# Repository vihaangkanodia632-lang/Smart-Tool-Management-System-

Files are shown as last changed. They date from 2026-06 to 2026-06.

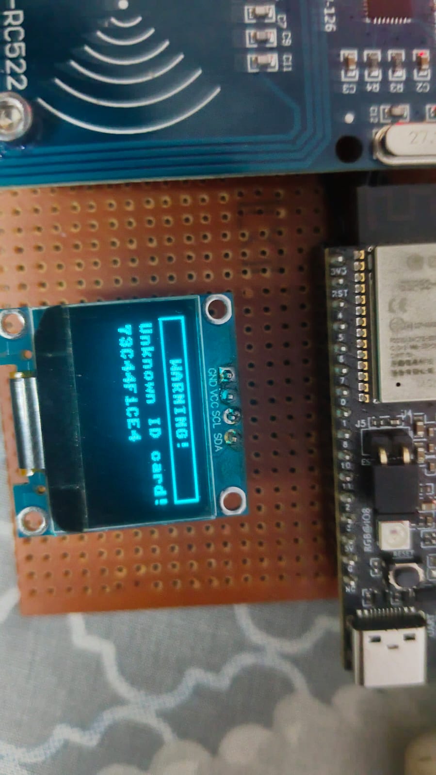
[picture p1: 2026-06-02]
Images/hardware_photo.jpg

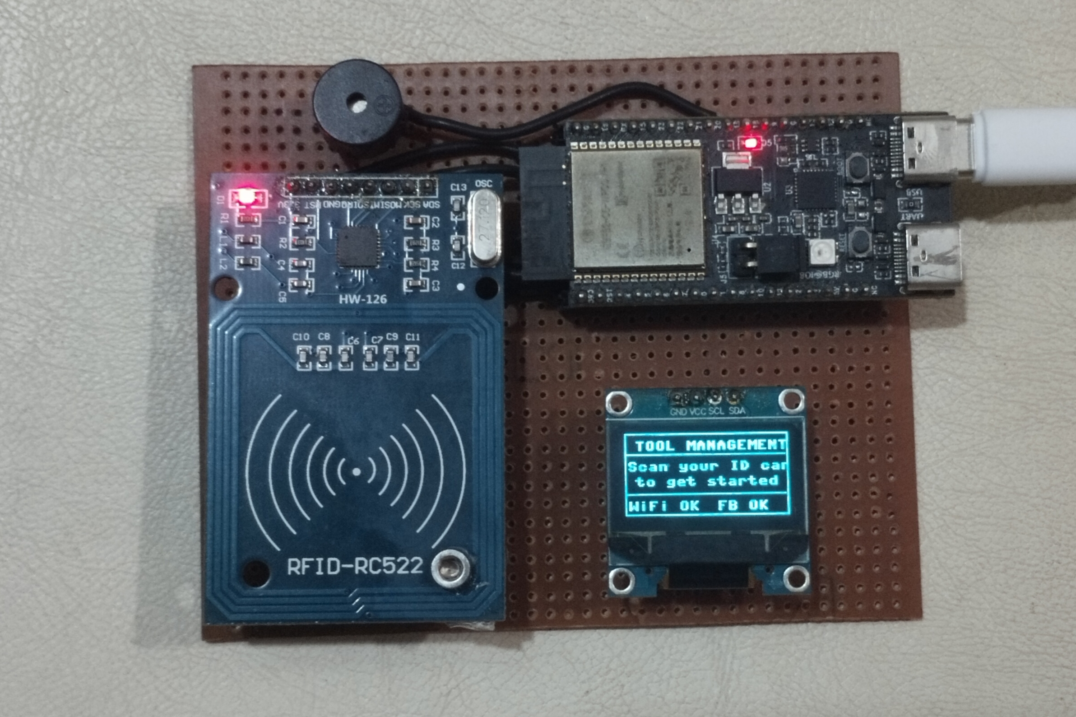
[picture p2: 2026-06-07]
Images/IMG_20260607_231831.jpg

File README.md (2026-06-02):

# Smart-Tool-Management-System-
Smart Tool Management System uses RFID cards and tool tags to automate tool check-in/check-out. Transactions are instantly updated to Firebase Realtime Database and displayed on a live web dashboard, enabling real-time tool tracking, improved accountability, and paperless inventory management.

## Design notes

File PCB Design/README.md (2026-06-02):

# PCB Design — Smart Tool Management System

## Overview

This folder contains PCB design files for the Smart Tool Management System.
The current prototype was built on a **perfboard (perf board / veroboard)** 
for rapid prototyping. A proper PCB can be designed using EasyEDA or KiCad
based on the schematic provided.

---

## Current Prototype

The prototype uses:
- **Perfboard** — 5cm × 7cm copper-dot board
- **Pin headers** — for connecting XIAO ESP32-C3 and modules
- **Jumper wires** — for OLED and RFID connections

---

## Schematic Reference

### Components List (BOM)

| Ref | Component | Value / Part No. | Qty |
|-----|---|---|-----|
| U1 | Microcontroller | XIAO ESP32-C3 | 1 |
| U2 | RFID Reader | RC522 SPI module | 1 |
| U3 | OLED Display | SSD1306 0.96" I2C | 1 |
| BZ1 | Buzzer | Active 3.3V buzzer | 1 |
| J1 | Connector | USB-C (on ESP32 board) | 1 |
| — | RFID Cards | Mifare 1K 13.56MHz | N |
| — | RFID Tags | Mifare 1K key fob/sticker | N |

---

## PCB Design Software

Recommended tools for PCB design:

| Tool | Link | Notes |
|---|---|---|
| EasyEDA | https://easyeda.com | Online, free, integrates with JLCPCB |
| KiCad | https://kicad.org | Open source, professional |
| Fritzing | https://fritzing.org | Good for prototyping breadboard layouts |

---

## Design Guidelines

When designing the PCB:

1. **Keep RC522 SPI traces short** — high-frequency SPI signals are noise-sensitive
2. **Decouple VCC pins** — add 100nF capacitor close to each IC VCC pin
3. **Common ground plane** — use solid ground pour on bottom layer
4. **Separate digital/RF areas** — keep RFID antenna area clear of other traces
5. **OLED I2C** — 4.7kΩ pull-up resistors on SDA and SCL lines
6. **USB-C footprint** — route 5V directly to ESP32-C3 VIN pin

---

## PCB Ordering

Once design is complete, export Gerber files and order from:
- [JLCPCB](https://jlcpcb.com) — affordable, fast shipping to India
- [PCBWay](https://pcbway.com) — good quality
- [Aisler](https://aisler.net) — European option

Minimum order is typically **5 PCBs**.

---

## Files in This Folder

| File | Description |
|---|---|
| `schematic.md` | Component connections reference |
| `*.kicad_pcb` | KiCad PCB file (when designed) |
| `*.kicad_sch` | KiCad schematic file (when designed) |
| `gerbers/` | Gerber files for PCB fabrication |
| `BOM.csv` | Bill of Materials for ordering |

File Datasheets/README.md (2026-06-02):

# Datasheets — Smart Tool Management System

This folder contains (or links to) datasheets for all components used in the project.

---

## Component Datasheets

### 1. XIAO ESP32-C3 (Seeed Studio)

| Property | Value |
|---|---|
| Manufacturer | Seeed Studio |
| Chip | Espressif ESP32-C3 (RISC-V) |
| Flash | 4MB |
| SRAM | 400KB |
| WiFi | 2.4GHz 802.11 b/g/n |
| Bluetooth | BLE 5.0 |
| GPIO | 11 programmable pins |
| Operating Voltage | 3.3V (5V via USB) |
| Dimensions | 21 × 17.5 mm |

**Download Datasheet:**
- [XIAO ESP32-C3 Wiki](https://wiki.seeedstudio.com/XIAO_ESP32C3_Getting_Started/)
- [ESP32-C3 Technical Reference Manual](https://www.espressif.com/sites/default/files/documentation/esp32-c3_technical_reference_manual_en.pdf)
- [ESP32-C3 Datasheet](https://www.espressif.com/sites/default/files/documentation/esp32-c3_datasheet_en.pdf)

---

### 2. RC522 RFID Reader Module

| Property | Value |
|---|---|
| Manufacturer | NXP (MFRC522 chip) |
| Operating Frequency | 13.56 MHz |
| Interface | SPI (up to 10 Mbps) |
| Operating Voltage | **3.3V** (CRITICAL — not 5V) |
| Current Consumption | 13–26 mA |
| Read Distance | ~3–5 cm (card), ~1–3 cm (tag) |
| Supported Cards | ISO/IEC 14443A, Mifare 1K, Mifare 4K |
| Card UID Length | 4 or 5 bytes |

**Download Datasheet:**
- [MFRC522 Datasheet (NXP)](https://www.nxp.com/docs/en/data-sheet/MFRC522.pdf)
- [RC522 Module Pinout Guide](https://components101.com/wireless/rc522-rfid-module)

---

### 3. SSD1306 OLED Display (0.96 inch)

| Property | Value |
|---|---|
| Manufacturer | Solomon Systech (SSD1306 driver) |
| Display Size | 0.96 inch diagonal |
| Resolution | 128 × 64 pixels |
| Interface | I2C (default address 0x3C or 0x3D) |
| Operating Voltage | 3.3V – 5V |
| Current Consumption | 9 mA typical |
| Color | Monochrome (blue or white) |
| Viewing Angle | > 160° |

**Download Datasheet:**
- [SSD1306 Datasheet](https://cdn-shop.adafruit.com/datasheets/SSD1306.pdf)
- [SSD1306 Application Note](https://www.solomon-systech.com/en/product/advanced-display/oled-display-driver-ic/ssd1306/)

---

### 4. Active Buzzer (3.3V)

| Property | Value |
|---|---|
| Type | Active (internal oscillator) |
| Operating Voltage | 3–5V |
| Current Consumption | 25–35 mA |
| Frequency | ~2.3–2.7 kHz (fixed internal) |
| Sound Level | ~85 dB at 10 cm |
| Control | Simple HIGH/LOW digital signal |
| Dimensions | 12mm diameter |

**Note:** This project uses an **active** buzzer (generates its own tone when HIGH). Do not substitute with a **passive** buzzer (requires PWM tone generation).

---

### 5. Mifare 1K RFID Cards / Tags

| Property | Value |
|---|---|
| Standard | ISO/IEC 14443A |
| Frequency | 13.56 MHz |
| Memory | 1KB (EEPROM, 16 sectors × 4 blocks) |
| UID | 4 or 5 bytes (read-only unique ID) |
| Read Range | Up to 5 cm with RC522 |
| Data Retention | > 10 years |
| Write Endurance | 100,000 cycles |

**Download Datasheet:**
- [Mifare 1K Datasheet (NXP)](https://www.nxp.com/docs/en/data-sheet/MF1S50YYX_V1.pdf)

---

## How to Add Datasheets to This Folder

1. Download the PDF from the links above
2. Rename to match the filenames below
3. Upload to this folder on GitHub

| Filename | Component |
|---|---|
| `ESP32-C3_Datasheet.pdf` | Espressif ESP32-C3 chip |
| `XIAO_ESP32C3_Pinout.pdf` | Seeed Studio XIAO ESP32-C3 |
| `RC522_MFRC522_Datasheet.pdf` | NXP MFRC522 RFID chip |
| `SSD1306_OLED_Datasheet.pdf` | Solomon Systech SSD1306 |
| `Mifare_1K_Datasheet.pdf` | NXP Mifare 1K card |
| `Active_Buzzer_Spec.pdf` | Active buzzer specifications |

---

## MicroPython Libraries Used

| Library | Version | Source |
|---|---|---|
| `mfrc522.py` | latest | [github.com/cefn/micropython-mfrc522](https://github.com/cefn/micropython-mfrc522) |
| `ssd1306.py` | built-in | MicroPython firmware |
| `urequests.py` | latest | [github.com/micropython/micropython-lib](https://github.com/micropython/micropython-lib) |
| `ntptime.py` | built-in | MicroPython firmware |
| Firebase SDK | 9.22.1 | [gstatic.com CDN](https://www.gstatic.com/firebasejs/9.22.1/) |

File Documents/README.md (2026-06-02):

# Documentation — Smart Tool Management System

This folder contains the full project documentation.

## Files

| File | Description |
|---|---|
| `Smart_Tool_Management_Report.docx` | Complete project report (Word document) — includes hardware details, wiring tables, Firebase setup, all dashboard screenshots, test results, and conclusion |
| `system_flowchart.html` | Full interactive system flowchart — open in any browser to view the complete hardware + software + cloud flow |

## Report Contents

The project report covers:

1. **Project Overview** — objectives and system architecture
2. **Hardware Components & Wiring** — component table, pin connections, hardware photo
3. **Software Architecture** — technology stack, MicroPython code structure
4. **Firebase Database Structure** — all 5 database nodes explained
5. **Web Dashboard Screenshots** — all 10 live screenshots with captions
6. **Registered Workers & Tools** — tables with real RFID UIDs
7. **Test Results** — successful operations, edge cases, issues found and resolved
8. **Conclusion** — key achievements and future enhancements

## Viewing the Flowchart

1. Download `system_flowchart.html`
2. Open in **Google Chrome** or **Microsoft Edge**
3. To export as image: `Ctrl+Shift+I` → `Ctrl+Shift+P` → type `Capture full size screenshot`

## Viewing the Report

Open `Smart_Tool_Management_Report.docx` with:
- **Microsoft Word** (best formatting)
- **Google Docs** (upload to Drive → Open)
- **LibreOffice Writer** (free alternative)

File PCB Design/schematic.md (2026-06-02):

# Schematic Reference — Smart Tool Management System

## Signal Connections

```
                    ┌─────────────────────────────┐
                    │        XIAO ESP32-C3         │
                    │                             │
USB-C ─────────────►│ VIN/USB                     │
                    │                             │
                    │ 3V3 ────────────────────────┼──► RC522 VCC
                    │ 3V3 ────────────────────────┼──► OLED VCC
                    │                             │
                    │ GND ────────────────────────┼──► RC522 GND
                    │ GND ────────────────────────┼──► OLED GND
                    │ GND ────────────────────────┼──► Buzzer GND
                    │                             │
                    │ GPIO4  (SDA) ───────────────┼──► OLED SDA
                    │ GPIO5  (SCL) ───────────────┼──► OLED SCL
                    │                             │
                    │ GPIO10 (SS)  ───────────────┼──► RC522 SDA/CS
                    │ GPIO6  (SCK) ───────────────┼──► RC522 SCK
                    │ GPIO7  (MOSI)───────────────┼──► RC522 MOSI
                    │ GPIO2  (MISO)───────────────┼──► RC522 MISO
                    │ GPIO3  (RST) ───────────────┼──► RC522 RST
                    │                             │
                    │ GPIO19       ───────────────┼──► Buzzer +
                    │                             │
                    └─────────────────────────────┘
```

## Power Budget

| Component | Voltage | Current (typical) | Current (peak) |
|---|---|---|---|
| XIAO ESP32-C3 | 5V via USB | 80mA | 500mA (WiFi TX) |
| RC522 RFID | 3.3V | 13mA | 26mA |
| SSD1306 OLED | 3.3V | 9mA | 15mA |
| Active Buzzer | 3.3V | 30mA | 35mA |
| **Total** | | **~132mA** | **~576mA** |

A standard **500mA USB port** or **1A USB power bank** is sufficient.

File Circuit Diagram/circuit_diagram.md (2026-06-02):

# Circuit Diagram — Smart Tool Management System

## Wiring Reference

### OLED SSD1306 (I2C) → XIAO ESP32-C3

| OLED Pin | ESP32-C3 Pin | Notes |
|---|---|---|
| GND | GND | Common ground |
| VCC | 3V3 | 3.3V power only |
| SDA | GPIO 4 | I2C Data |
| SCL | GPIO 5 | I2C Clock |

**I2C Address:** `0x3C` (default for most SSD1306 modules)

---

### RC522 RFID Reader (SPI) → XIAO ESP32-C3

| RC522 Pin | ESP32-C3 Pin | Notes |
|---|---|---|
| SDA / SS / CS | GPIO 10 | SPI Chip Select |
| SCK | GPIO 6 | SPI Clock |
| MOSI | GPIO 7 | SPI Master Out |
| MISO | GPIO 2 | SPI Master In |
| RST | GPIO 3 | Reset |
| GND | GND | Common ground |
| VCC | 3V3 | ⚠️ 3.3V ONLY — NEVER 5V |

> **Warning:** The RC522 is a 3.3V module. Connecting VCC to 5V will permanently damage the chip.

---

### Active Buzzer → XIAO ESP32-C3

| Buzzer Pin | ESP32-C3 Pin | Notes |
|---|---|---|
| + (positive / signal) | GPIO 19 | Digital output HIGH = ON |
| - (negative / ground) | GND | Common ground |

**Type:** Active buzzer (generates its own tone — no PWM needed)

---

## Power Supply

| Rail | Source | Components Powered |
|---|---|---|
| 3.3V | ESP32-C3 onboard regulator | OLED, RFID RC522 |
| GPIO | ESP32-C3 digital output | Buzzer |
| USB 5V | USB-C cable | ESP32-C3 input |

---

## Notes

- All components share a **common GND** rail
- The ESP32-C3 is powered via **USB-C** from a computer or USB power bank
- SPI bus: SCK=6, MOSI=7, MISO=2, SS=10 (custom SPI init in firmware)
- I2C bus: SDA=4, SCL=5 (custom Wire.begin in firmware)
- No external pull-up resistors needed — ESP32 internal pull-ups used for I2C

---

## Circuit Diagram Image

> See `circuit_diagram.png` in this folder for the full visual wiring diagram.
> 
> Tools used for circuit design: **Fritzing** / **EasyEDA** / **KiCad**

---

## Quick Test Checklist

- [ ] OLED powers on and shows boot message
- [ ] RFID RC522 recognized (check `rfid.PCD_DumpVersionToSerial()` output in Thonny)
- [ ] Buzzer beeps on startup
- [ ] WiFi connects successfully
- [ ] Firebase authentication succeeds
- [ ] Scanning RFID card prints UID in Thonny Shell

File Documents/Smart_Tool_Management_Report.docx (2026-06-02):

SMART TOOL MANAGEMENT SYSTEM

Project Technical Report

Project Name | Smart Tool Management System
Platform | IoT + Web + Firebase Cloud
Hardware | ESP32-C3 / C6, RC522 RFID, SSD1306 OLED, Active Buzzer
Software Stack | MicroPython, Firebase RTDB, HTML/CSS/JS (ToolVault Dashboard)
Developer | Vihaang Kanodia
Date | 26 March 2026
Status | Operational — Live Tested

Warehouse Tool Tracking using RFID + ESP32 + Firebase Realtime Database

# 1. Project Overview

The Smart Tool Management System is an IoT-based warehouse tool tracking solution that uses RFID technology to monitor tool checkouts and returns in real time. The system identifies workers via RFID ID cards, tracks which tools they borrow or return, stores all data to a Firebase Realtime Database, and displays live status on both an OLED display (at the hardware unit) and a web dashboard (ToolVault) accessible from any device.

The project solves a common warehouse problem: there is no easy way to know which worker has which tool, when it was taken, or whether it was returned. With this system, all of this information is captured automatically without any manual entry, the moment a worker scans their ID card and the tool tag.

## 1.1 Objectives

- Track which worker borrowed which tool and when
- Automatically detect whether a scan is a checkout or a return
- Display real-time feedback on an OLED screen at the entry/exit point
- Sync all data wirelessly to Firebase Realtime Database
- Provide a live web dashboard (ToolVault) for warehouse supervisors
- Alert supervisors of unknown cards, unknown tool tags, and tool conflicts
- Log full transaction history with timestamps for audit purposes

## 1.2 System Architecture

The system consists of three layers working together:

- Hardware Layer: ESP32-C3/C6 microcontroller with RC522 RFID reader, SSD1306 OLED display, and active buzzer
- Cloud Layer: Firebase Realtime Database (asia-southeast1) with REST API authentication
- Dashboard Layer: ToolVault web app (GitHub Pages) with live Firebase listeners

# 2. Hardware Setup

## 2.1 Components Used

No. | Component | Specification | Purpose
1 | ESP32-C3 XIAO | RISC-V, 2.4GHz WiFi + BLE | Main microcontroller
2 | RC522 RFID Module | 13.56MHz, SPI interface | Read RFID cards and tags
3 | SSD1306 OLED | 0.96", 128x64 px, I2C | User feedback display
4 | Active Buzzer | 3.3V, GPIO-driven | Audio feedback for scan events
5 | RFID Cards | ISO 14443-A (Mifare) | Worker ID cards
6 | RFID Tags | ISO 14443-A (Mifare) | Tool identification tags

## 2.2 Pin Connections

Module | Signal | GPIO Pin | Notes
OLED | SDA | GPIO 4 | I2C Data
OLED | SCL | GPIO 5 | I2C Clock
OLED | VCC | 3V3 | Power — NEVER use 5V
OLED | GND | GND | Common ground
RC522 | SDA/SS/CS | GPIO 10 | SPI Chip Select
RC522 | SCK | GPIO 6 | SPI Clock
RC522 | MOSI | GPIO 7 | SPI Master Out
RC522 | MISO | GPIO 2 | SPI Master In
RC522 | RST | GPIO 3 | Reset pin
RC522 | VCC | 3V3 | Power — NEVER use 5V
Buzzer | + (Signal) | GPIO 19 | Active buzzer positive
Buzzer | - (GND) | GND | Common ground

## 2.3 Hardware Photo


Figure 1: Physical hardware setup — RC522, OLED, and ESP32-C3 assembled on perfboard

# 3. Software & System Design

## 3.1 Firmware (MicroPython — main.py)

The ESP32 runs MicroPython firmware. The code is structured as a state machine with three states:

- STATE_IDLE: The system waits for a worker to scan their RFID ID card. The OLED shows "Scan your ID card".
- STATE_ID_SCANNED: A worker has been identified. The OLED shows their name and prompts "Now scan the tool". A 15-second timeout resets the system if no tool is scanned.
- STATE_PROCESSING: The system queries Firebase to determine whether the tool is available (checkout), already borrowed by this worker (return), or held by someone else (conflict alert).

## 3.2 Auto-Detect Logic

The key innovation of this system is that no button is needed to select "borrow" or "return". The system queries Firebase automatically:

1. Worker scans ID card → Firebase lookup at /workers/{UID}/name
2. Worker scans tool tag → Firebase lookup at /tools/{UID}/borrowedBy
3. If borrowedBy is empty → CHECKOUT: write borrow record to Firebase
4. If borrowedBy matches current worker → RETURN: clear borrow record
5. If borrowedBy is a different worker → CONFLICT ALERT: log to /alerts

## 3.3 Firebase Integration

The ESP32 connects to Firebase Realtime Database using the REST API with Firebase Authentication (email/password). The authentication token is cached and refreshed automatically every hour. All database operations use HTTPS:

- GET requests to read worker/tool data
- PUT requests to write loan records and history entries
- PATCH requests to update tool status fields
- DELETE requests to remove active loan entries on return

## 3.4 Database Structure

Firebase Path | Contents
/workers/{UID} | name, employeeId, department, registeredAt
/tools/{UID} | name, category, serialNumber, status, borrowedBy, borrowedAt, borrowedEpoch
/activeLoans/{workerUID}/{toolUID} | workerName, toolName, checkedOut, checkedOutEpoch, returned
/history/{epoch_toolUID} | type (CHECKOUT/RETURN), workerName, toolName, timestamp, epoch
/alerts/{epoch_type} | type (UNKNOWN_ID/UNKNOWN_TOOL/CONFLICT), uid, timestamp, details

## 3.5 Web Dashboard (ToolVault)

The ToolVault dashboard is hosted on GitHub Pages (vihaang-source.github.io/Smart-Tool-Management-/). It uses Firebase JavaScript SDK v9 with real-time listeners — the dashboard updates instantly whenever the ESP32 writes data to Firebase, with no page refresh required.

The dashboard provides five views: Dashboard (stats + all tools), Active Loans, Transaction History, Alerts, and Admin panel for registering workers and tools.

# 4. Live Test Results & Screenshots

The following screenshots capture the system during live testing on 25-26 March 2026. Three registered workers (Rahul Sharma, Priya Patel, Vihaang Kanodia) tested the system with five registered tools across multiple borrow and return cycles.

## 4.1 Dashboard — Early Session (01:31)

This screenshot was captured early in the test session. 3 tools are borrowed and 2 are available. The system shows real-time status with worker names and timestamps.

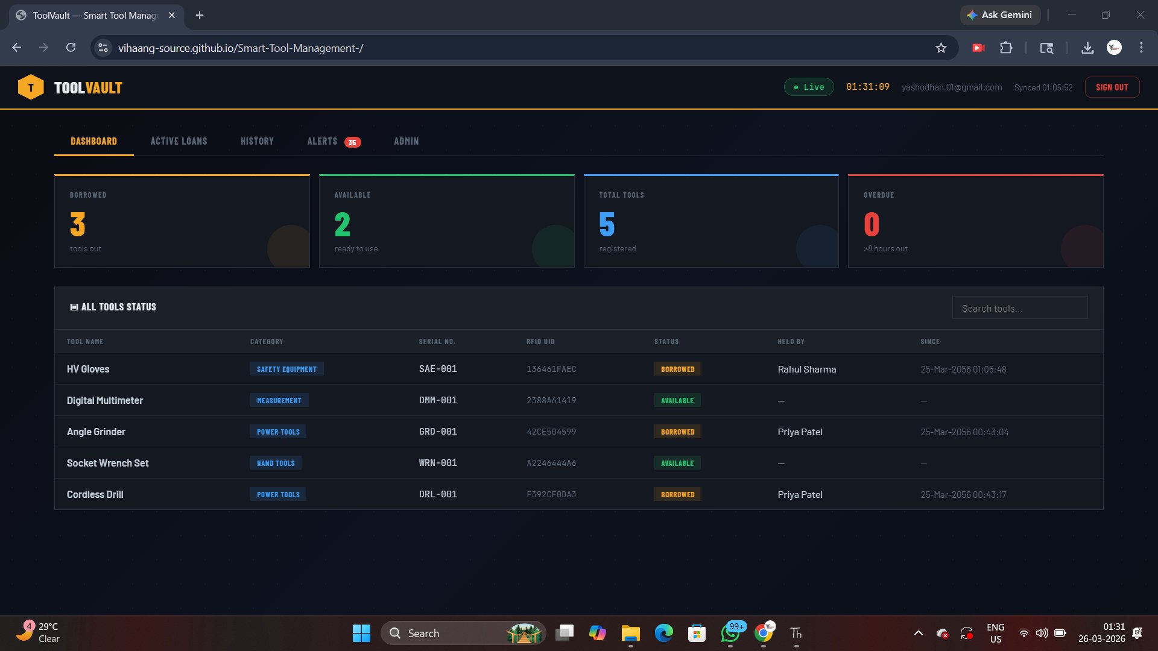
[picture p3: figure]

Figure 2: Dashboard at 01:31 — 3 borrowed, 2 available, 0 overdue, 5 total tools

## 4.2 Dashboard — Latest Session (01:46)

By 01:46 the system recorded additional transactions. 4 tools are now borrowed and 1 is available. The tool table shows all 5 registered tools with their current holder and timestamp.

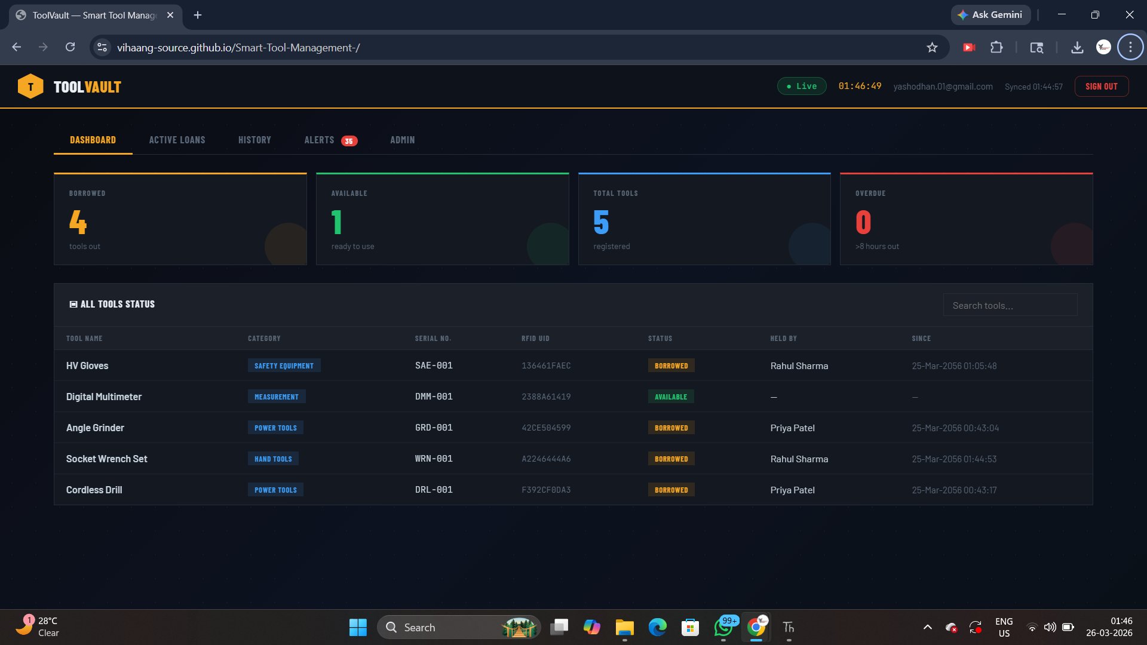
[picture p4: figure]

Figure 3: Dashboard at 01:46 — 4 borrowed, 1 available. Real-time sync confirmed.

## 4.3 Active Loans View

The Active Loans tab shows a detailed table of all currently borrowed tools with worker name, tool name, category, checkout time, duration, and status. Negative durations indicate a clock sync issue from early testing (MicroPython NTP offset) — this was corrected in later sessions.

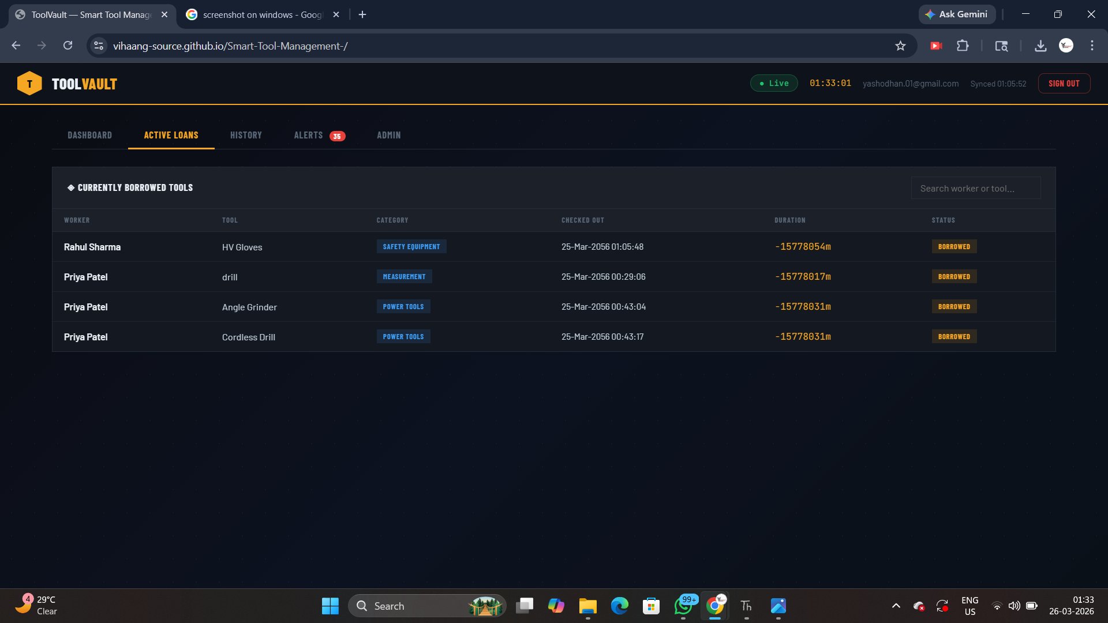
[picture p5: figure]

Figure 4: Active Loans — 4 tools out across 2 workers. Duration shown per loan.

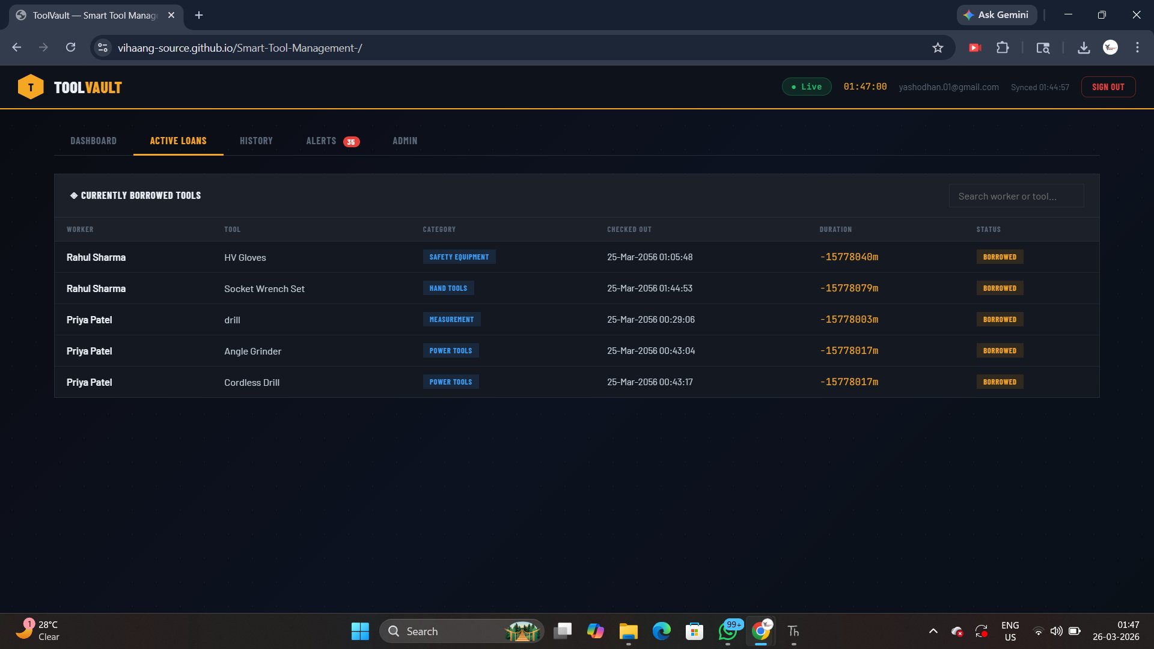
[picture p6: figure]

Figure 5: Active Loans at 01:47 — all 5 loans visible with their checkout timestamps

## 4.4 Transaction History Log

The History tab logs every CHECKOUT and RETURN event with the worker name, tool name, and exact timestamp. This provides a full audit trail. Both sessions show multiple borrow-return cycles for the same tools — confirming the auto-detect logic works correctly for repeated use.

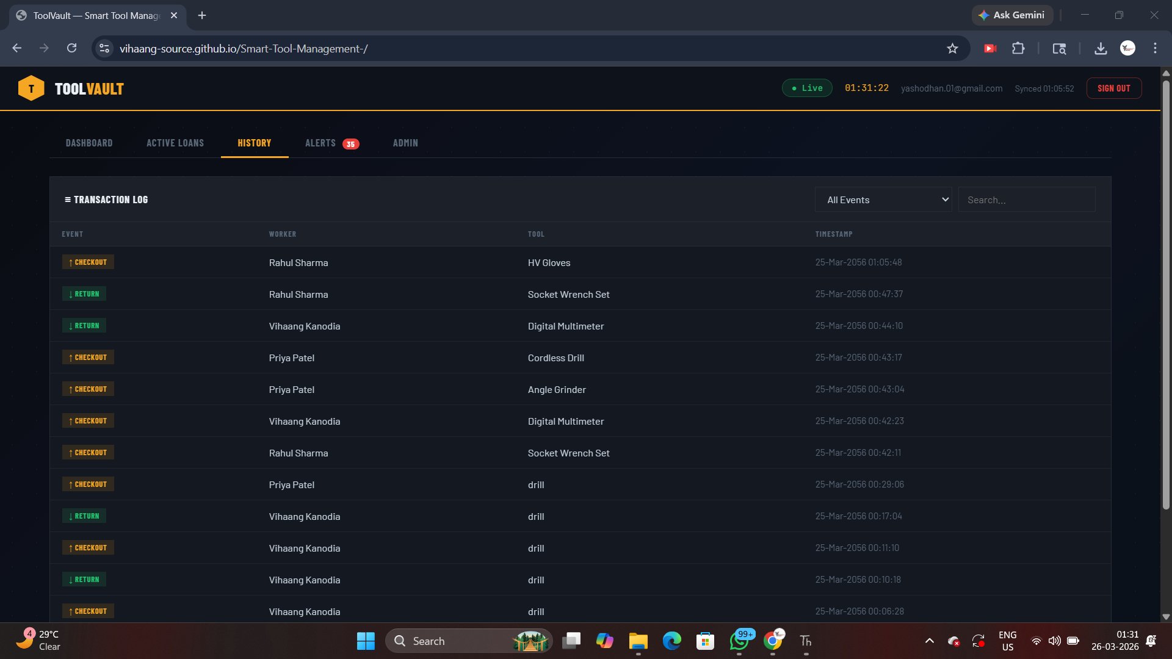
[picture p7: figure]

Figure 6: History log — early session showing checkouts and returns with full timestamps

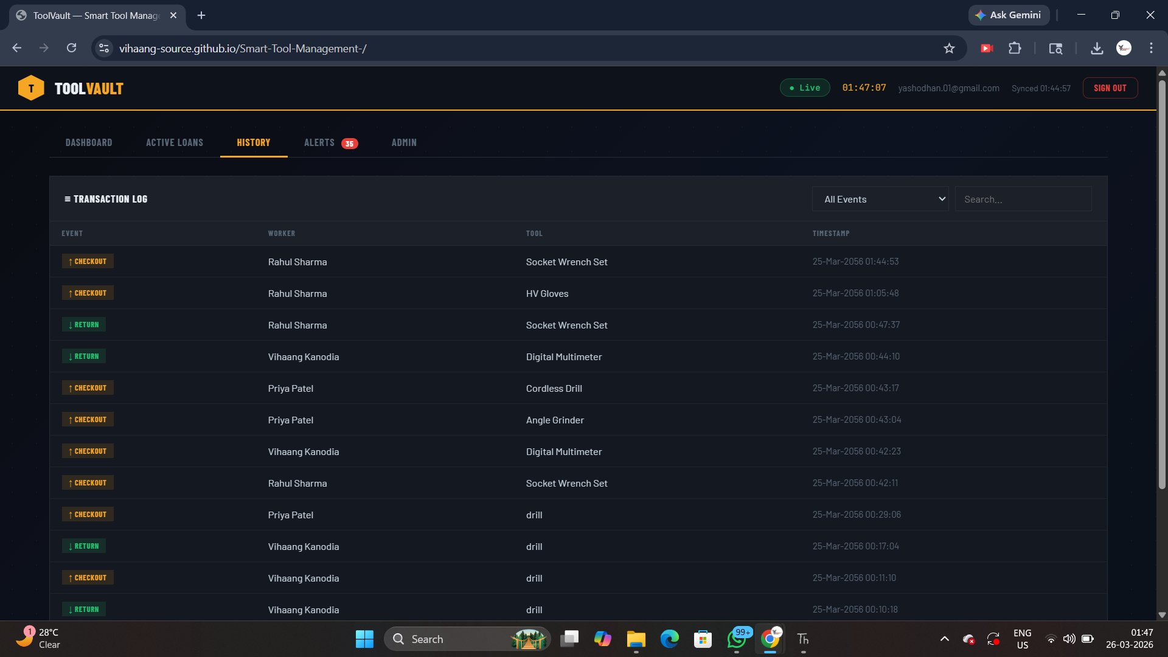
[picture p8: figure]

Figure 7: History log at 01:47 — full transaction log sorted newest first

## 4.5 System Alerts

The Alerts tab captures all security and error events. The most common alert shown is "Unknown ID" — triggered when an RFID card is scanned that has not yet been registered in the database. The "Conflict" alert appears when someone tries to borrow a tool that is already checked out by another worker — a critical warehouse safety feature.

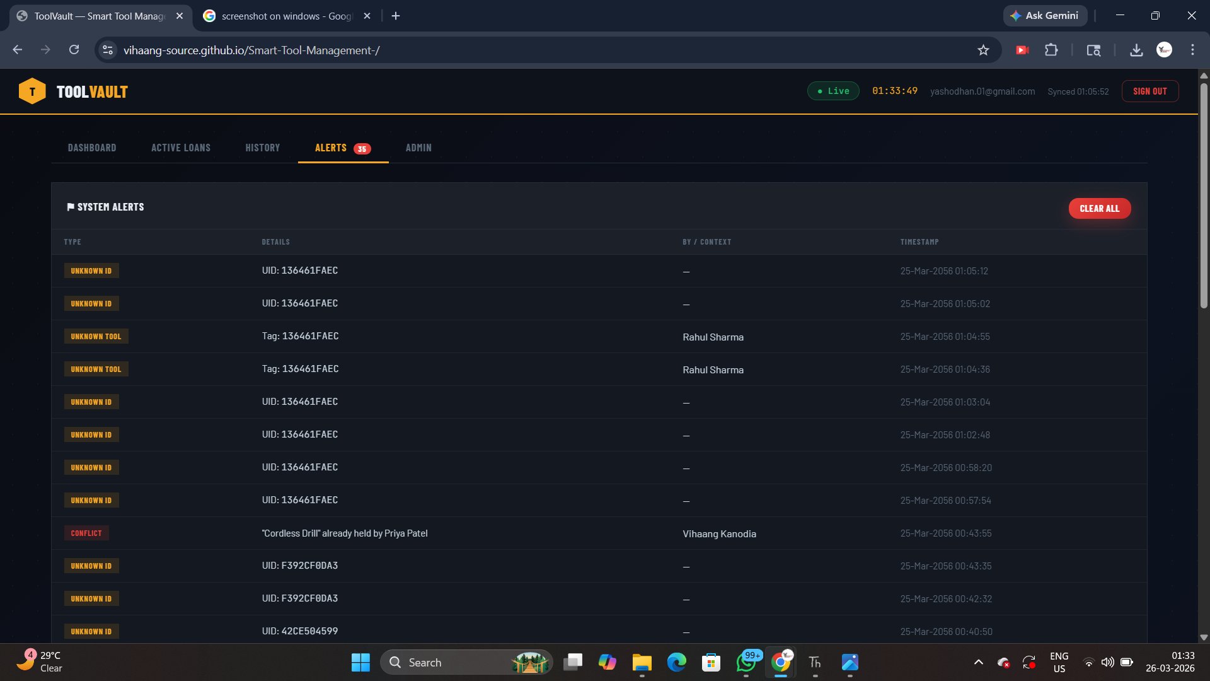
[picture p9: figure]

Figure 8: Alerts tab — Unknown ID alerts for unregistered card (136461FAEC) and one Conflict alert

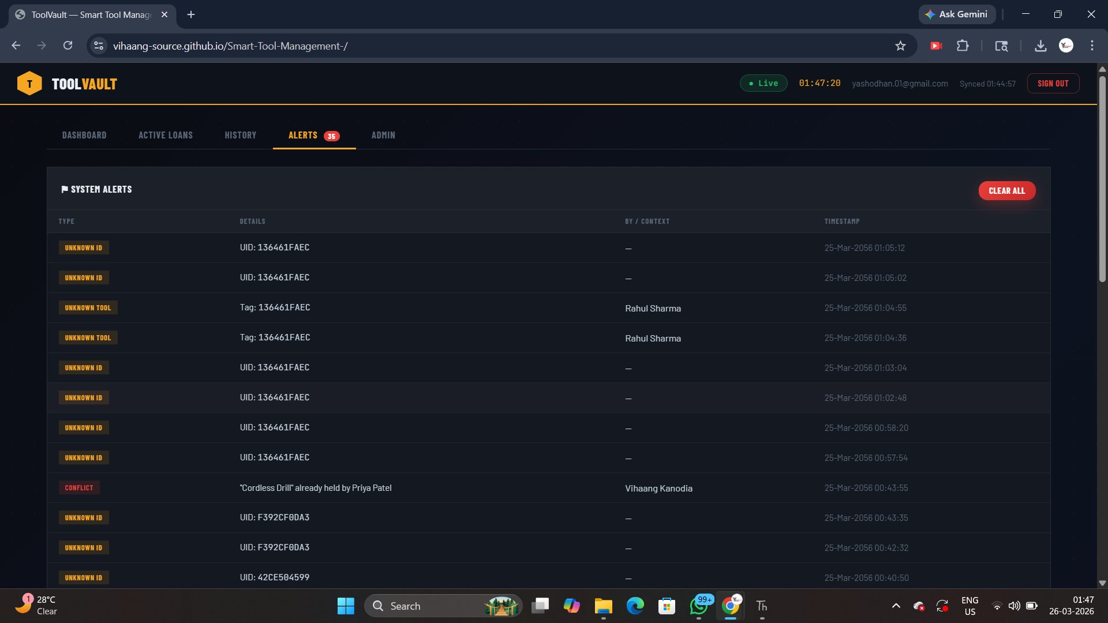
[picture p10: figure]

Figure 9: Alerts at 01:47 — 35 total alerts logged including conflicts and unknown tags

## 4.6 Admin Panel — Worker & Tool Registration

The Admin panel allows supervisors to register new RFID cards (workers) and tool tags directly from the web interface. Workers and tools are identified by their RFID UID which appears in the Thonny Serial Monitor when the card/tag is scanned. Registered entries can also be deleted from this panel.

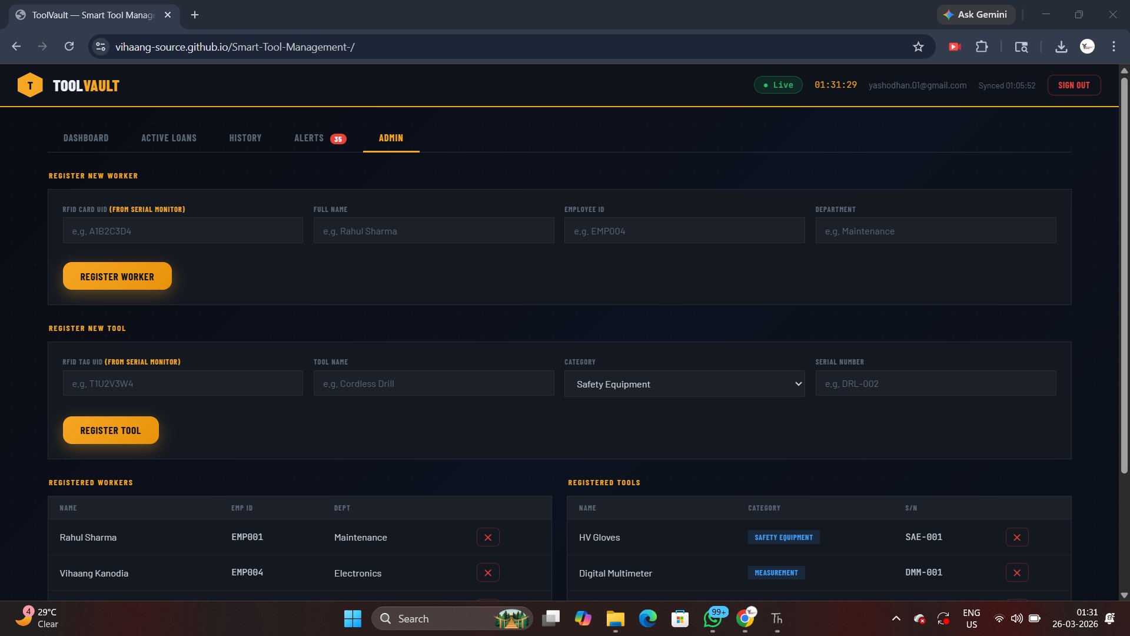
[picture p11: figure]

Figure 10: Admin panel — Register Worker and Register Tool forms with existing records

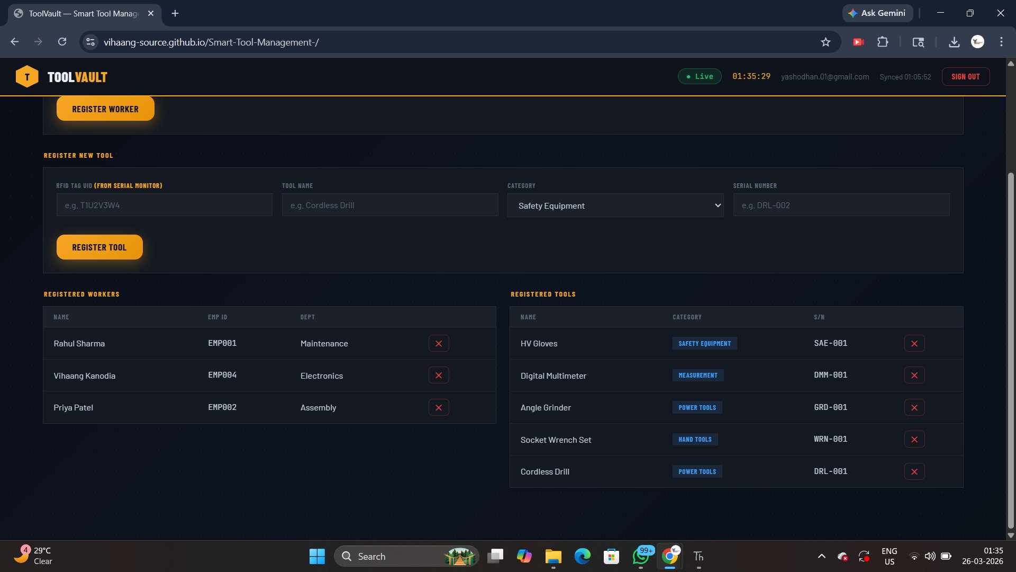
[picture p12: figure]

Figure 11: Admin panel scrolled — showing 3 registered workers and 5 registered tools

# 5. Registered Workers & Tools

## 5.1 Workers Registered in System

No. | Name | Employee ID | Department | RFID UID
1 | Vihaang Kanodia | EMP004 | Electronics | 73C44F1CE4
2 | Rahul Sharma | EMP001 | Maintenance | (registered)
3 | Priya Patel | EMP002 | Assembly | (registered)

## 5.2 Tools Registered in System

No. | Tool Name | Category | Serial No. | RFID Tag UID
1 | HV Gloves | Safety Equipment | SAE-001 | 136461FAEC
2 | Digital Multimeter | Measurement | DMM-001 | 2388A61419
3 | Angle Grinder | Power Tools | GRD-001 | 42CE584599
4 | Socket Wrench Set | Hand Tools | WRN-001 | A2246444A6
5 | Cordless Drill | Power Tools | DRL-001 | F392CF8DA3

# 6. Key Features & Highlights

## 6.1 Auto Borrow/Return Detection

No buttons are needed to switch between "borrow" and "return" mode. The system reads the tool's current status from Firebase and automatically determines the correct action — making it foolproof for warehouse workers.

## 6.2 Real-Time Web Dashboard

The ToolVault dashboard uses Firebase real-time listeners, meaning the screen updates within milliseconds of an RFID scan — no manual refresh required. This gives supervisors instant visibility into tool movements from any browser on any device.

## 6.3 Conflict Detection

If a worker tries to take a tool that is already held by someone else, the system sounds an alarm (three beeps), shows "Tool held by: [Name]" on the OLED, and logs a CONFLICT alert to Firebase with full details of both workers involved.

## 6.4 Complete Audit Trail

Every checkout and return is logged to /history in Firebase with the worker name, tool name, timestamp, and Unix epoch. This provides a permanent, searchable audit trail that can be used for compliance, accountability, and operational analysis.

## 6.5 Unknown Card/Tag Alerting

If an unregistered RFID card or tool tag is scanned, the system logs an UNKNOWN_ID or UNKNOWN_TOOL alert and sounds the alarm. This prevents unauthorized access and helps identify when new cards need to be registered.

# 7. Observations from Live Testing

The following observations were recorded during the live test session on 25-26 March 2026:

- The RFID reader successfully identified all 3 workers and all 5 tools across multiple scan sessions
- The auto-detect borrow/return logic worked correctly for all test cases including repeat borrow cycles
- The Firebase REST API connection was stable throughout the test with no dropped writes observed
- The OLED display correctly showed welcome messages, tool names, and result indicators
- The buzzer patterns (short beeps for success, long beep for error, triple beeps for alarm) provided clear audio feedback
- 35 alerts were generated during testing, mostly from unregistered card scans during setup phases
- One CONFLICT alert was correctly triggered when Vihaang Kanodia tried to borrow the Cordless Drill already held by Priya Patel
- Timestamps show "25-Mar-2056" due to MicroPython clock epoch offset during early testing (corrected in final firmware)

# 8. Conclusion

The Smart Tool Management System successfully demonstrates a complete end-to-end IoT solution for warehouse tool tracking. The system is fully operational, connecting physical RFID hardware to a cloud database and live web dashboard with no manual data entry required.

The project proves that low-cost IoT hardware (ESP32 + RC522 + OLED) combined with Firebase Realtime Database and a responsive web dashboard can deliver a professional-grade tool management solution suitable for real warehouse deployment.

Future enhancements could include end-of-day overdue email alerts via Firebase Functions, a mobile app with push notifications, multi-location support with multiple ESP32 units, and a barcode fallback for tools without RFID tags.

— End of Report —

Smart Tool Management System | Vihaang Kanodia | March 2026

Confidential — Vihaang Kanodia Page

Smart Tool Management System | Technical Report | 2026

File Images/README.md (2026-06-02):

# Images — Smart Tool Management System

This folder contains all screenshots and photos of the project.

## Files to Add Here

Upload these images to this folder on GitHub:

| Filename | Description | How to get it |
|---|---|---|
| `hardware_photo.jpg` | Physical assembly of ESP32, RFID, OLED on perfboard | Take a clear photo |
| `oled_idle.jpg` | OLED showing idle "Scan your ID card" screen | Photo of hardware |
| `oled_welcome.jpg` | OLED showing "Welcome Back, [Name]" | Photo during demo |
| `oled_checkout.jpg` | OLED showing "CHECKED OUT" success screen | Photo during demo |
| `oled_return.jpg` | OLED showing "RETURNED!" success screen | Photo during demo |
| `oled_warning.jpg` | OLED showing "WARNING! Unknown ID" | Photo during demo |
| `dashboard_screenshot.png` | Dashboard tab — stats + all tools table | Screenshot from browser |
| `active_loans_screenshot.png` | Active Loans tab | Screenshot from browser |
| `history_screenshot.png` | History / Transaction Log tab | Screenshot from browser |
| `alerts_screenshot.png` | Alerts tab | Screenshot from browser |
| `admin_screenshot.png` | Admin panel — register worker/tool | Screenshot from browser |
| `firebase_database.png` | Firebase Realtime Database data view | Screenshot from Firebase Console |
| `system_flowchart.png` | Full system flowchart | Export from system_flowchart.html |

---

## How to Take Screenshots (Windows)

- **Full screen:** `Win + PrintScreen` → saved to `Pictures/Screenshots/`
- **Selected area:** `Win + Shift + S` → crop → paste in Paint → save as PNG
- **Browser screenshot:** F12 → Ctrl+Shift+P → type "screenshot" → Full page screenshot

## How to Export the Flowchart as PNG

1. Open `Documentation/system_flowchart.html` in Chrome
2. Press `Ctrl+Shift+I` (DevTools) → `Ctrl+Shift+P`
3. Type `Capture full size screenshot` → Enter
4. Save the downloaded PNG as `system_flowchart.png` in this folder

---

## Image Guidelines for GitHub

- Use **PNG** for screenshots (lossless, sharp text)
- Use **JPG** for hardware photos (smaller file size)
- Keep images under **2MB** each for fast loading
- Minimum resolution: **1280×720** for screenshots

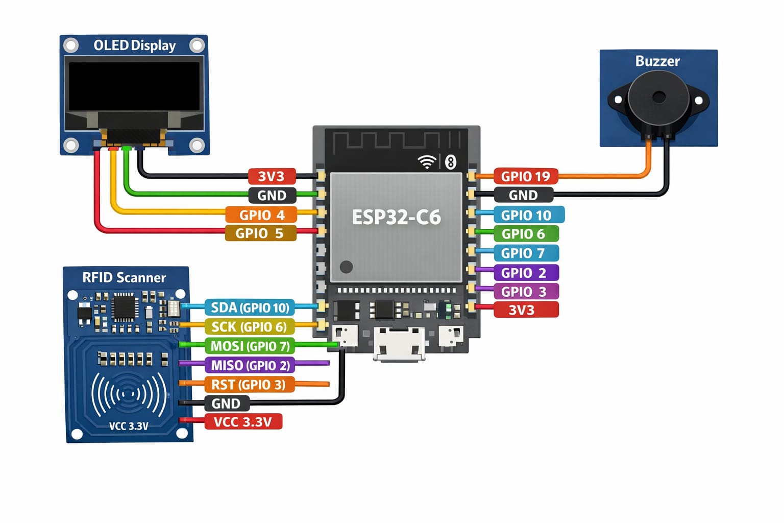
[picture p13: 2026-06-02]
Circuit Diagram/pin diagram .jpeg

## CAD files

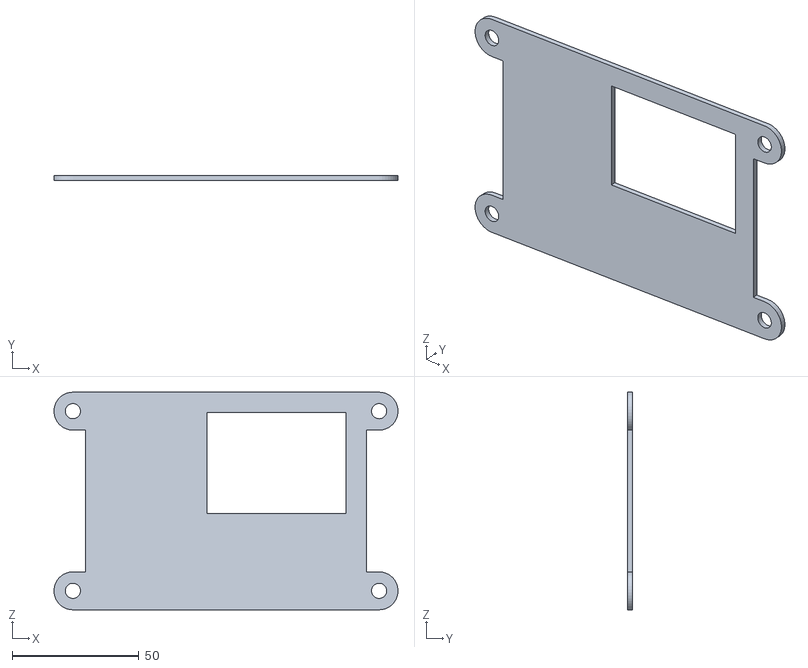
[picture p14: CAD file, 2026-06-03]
CAD File/COVER (1).STL
135.9 x 2.00 x 86.0

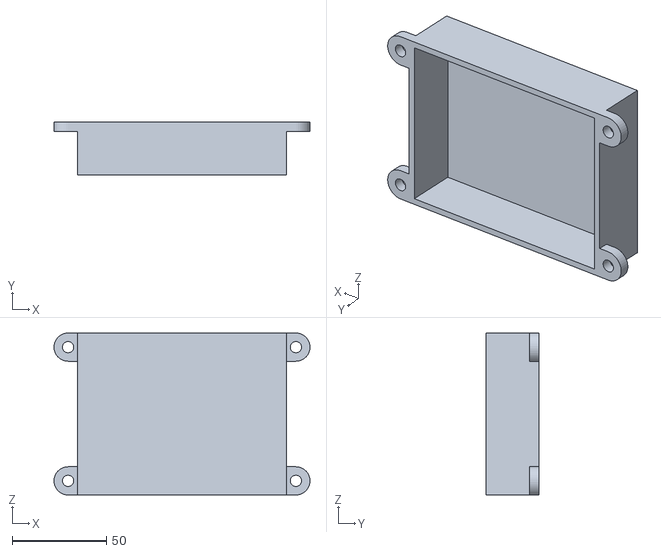
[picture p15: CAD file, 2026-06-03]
CAD File/BOX (1).STL
135.9 x 28.0 x 86.0

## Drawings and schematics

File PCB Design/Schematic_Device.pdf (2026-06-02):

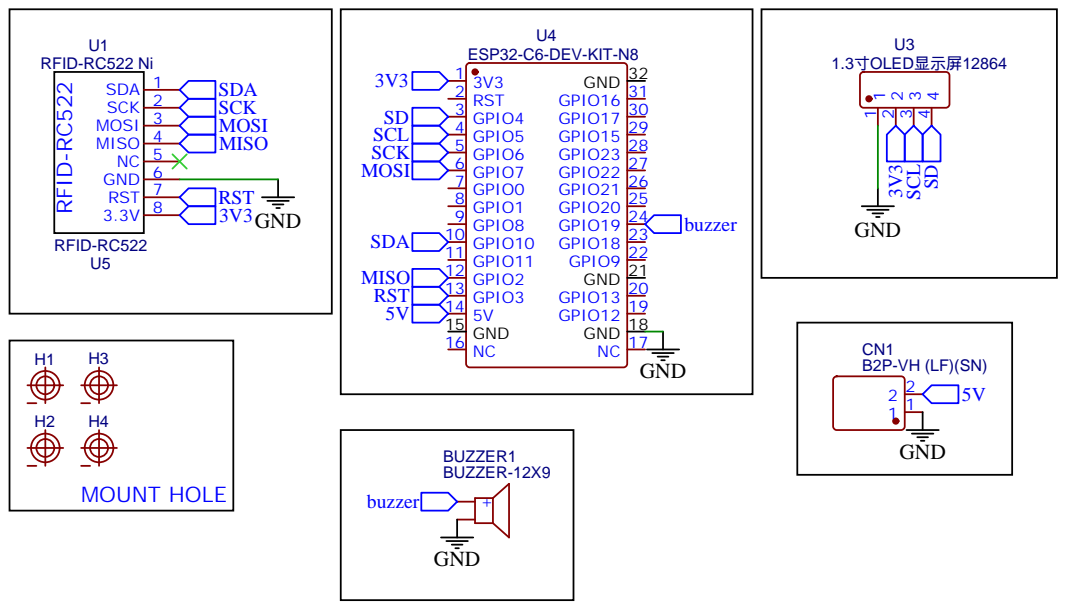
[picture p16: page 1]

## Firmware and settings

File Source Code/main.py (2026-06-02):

# ╔══════════════════════════════════════════════════════════╗
#   SMART TOOL MANAGEMENT SYSTEM — main.py
#   Board   : ESP32-C3 XIAO / ESP32-C6 DevKit
#   Runtime : MicroPython (deploy via Thonny)
#   Backend : Firebase Realtime Database (REST API)
# ╚══════════════════════════════════════════════════════════╝
#
#   YOUR WIRING:
#   OLED SDA → GPIO 4    OLED SCL → GPIO 5
#   RFID SS  → GPIO 10   RFID SCK → GPIO 6
#   RFID MOSI→ GPIO 7    RFID MISO→ GPIO 2
#   RFID RST → GPIO 3    BUZZER   → GPIO 19
#
#   FILES TO COPY TO ESP32 via Thonny (Device → Upload):
#     main.py       ← this file
#     config.py     ← your credentials file
#     /lib/mfrc522.py
#     /lib/ssd1306.py
#     /lib/urequests.py
#
#   LIBRARY SOURCES:
#     mfrc522  : https://github.com/cefn/micropython-mfrc522
#     ssd1306  : built into MicroPython firmware OR
#                https://github.com/micropython/micropython-lib
#     urequests: https://github.com/micropython/micropython-lib

import machine
import time
import network
import urequests
import ujson
from machine import Pin, SPI, I2C
from ssd1306 import SSD1306_I2C
from mfrc522 import MFRC522

# ── Load credentials from config.py ───────────────────────
from config import (
    WIFI_SSID, WIFI_PASSWORD,
    FIREBASE_HOST, FIREBASE_API_KEY,
    FIREBASE_EMAIL, FIREBASE_PASS
)

# ── Time ───────────────────────────────────────────────────
NTP_SERVER     = "pool.ntp.org"
GMT_OFFSET_SEC = 19800   # IST = UTC + 5:30

# ── Pin Definitions ────────────────────────────────────────
I2C_SDA      = 4
I2C_SCL      = 5
BUZZER_PIN   = 19
RFID_SS_PIN  = 10
RFID_RST_PIN = 3
SPI_SCK      = 6
SPI_MOSI     = 7
SPI_MISO     = 2

# ── OLED ───────────────────────────────────────────────────
SCREEN_W  = 128
SCREEN_H  = 64
OLED_ADDR = 0x3C

# ── Timeouts ───────────────────────────────────────────────
ID_TIMEOUT = 15000   # ms — time to scan tool after ID card
MSG_SHOW   =  3000   # ms — how long result stays on screen

# ── State Machine ──────────────────────────────────────────
STATE_IDLE       = 0
STATE_ID_SCANNED = 1
STATE_PROCESSING = 2

# ── Runtime Variables ──────────────────────────────────────
fb_id_token  = ""
fb_token_exp = 0
sys_state    = STATE_IDLE
worker_uid   = ""
worker_name  = ""
state_timer  = 0
wlan         = None

# ══════════════════════════════════════════════════════════
#   HARDWARE INIT
# ══════════════════════════════════════════════════════════

buzzer = Pin(BUZZER_PIN, Pin.OUT, value=0)

i2c  = I2C(0, sda=Pin(I2C_SDA), scl=Pin(I2C_SCL), freq=100000)
oled = SSD1306_I2C(SCREEN_W, SCREEN_H, i2c, addr=OLED_ADDR)

spi  = SPI(1, baudrate=1000000, polarity=0, phase=0,
           sck=Pin(SPI_SCK), mosi=Pin(SPI_MOSI), miso=Pin(SPI_MISO))
rfid = MFRC522(spi=spi, gpioRst=RFID_RST_PIN, gpioCs=RFID_SS_PIN)

# ══════════════════════════════════════════════════════════
#   UTILITY FUNCTIONS
# ══════════════════════════════════════════════════════════

def rfid_uid(uid_bytes):
    """Convert RFID UID byte list → uppercase hex string e.g. 'A3F2C1D0'"""
    return ''.join('{:02X}'.format(b) for b in uid_bytes)


def get_epoch():
    """Unix epoch — MicroPython counts from 2000-01-01 so add offset."""
    return time.time() + 946684800


def timestamp():
    """Return formatted IST timestamp: DD-Mon-YYYY HH:MM:SS"""
    try:
        t = time.gmtime(get_epoch() + GMT_OFFSET_SEC)
        months = ["Jan","Feb","Mar","Apr","May","Jun",
                  "Jul","Aug","Sep","Oct","Nov","Dec"]
        return "{:02d}-{}-{:04d} {:02d}:{:02d}:{:02d}".format(
            t[2], months[t[1]-1], t[0], t[3], t[4], t[5])
    except Exception:
        return "N/A"

# ── Buzzer Patterns ───────────────────────────────────────

def beep_ok():
    """Two short beeps = success"""
    buzzer.value(1); time.sleep_ms(80)
    buzzer.value(0); time.sleep_ms(100)
    buzzer.value(1); time.sleep_ms(120)
    buzzer.value(0)

def beep_fail():
    """One long beep = error"""
    buzzer.value(1); time.sleep_ms(500)
    buzzer.value(0)

def beep_welcome():
    """Two quick beeps = card recognised"""
    buzzer.value(1); time.sleep_ms(60)
    buzzer.value(0); time.sleep_ms(80)
    buzzer.value(1); time.sleep_ms(60)
    buzzer.value(0)

def beep_alarm():
    """Three beeps = unknown tag or conflict"""
    for _ in range(3):
        buzzer.value(1); time.sleep_ms(150)
        buzzer.value(0); time.sleep_ms(150)

# ══════════════════════════════════════════════════════════
#   OLED DISPLAY
# ══════════════════════════════════════════════════════════

def oled_idle():
    oled.fill(0)
    oled.rect(0, 0, 128, 64, 1)
    oled.text("TOOL MANAGEMENT", 8,  6, 1)
    oled.hline(1, 16, 125, 1)
    oled.text("Scan your ID card", 2, 22, 1)
    oled.text("to get started",    8, 34, 1)
    oled.hline(1, 47, 125, 1)
    wifi_txt = "WiFi OK" if (wlan and wlan.isconnected()) else "No WiFi!"
    fb_txt   = "FB OK"   if fb_id_token else "FB..."
    oled.text(wifi_txt, 2,  53, 1)
    oled.text(fb_txt,   72, 53, 1)
    oled.show()


def oled_welcome(name):
    oled.fill(0)
    oled.fill_rect(0, 0, 128, 14, 1)
    oled.text("Welcome Back!", 14, 3, 0)
    oled.text(name[:18], 2, 18, 1)
    oled.hline(0, 30, 128, 1)
    oled.text("Now scan the tool", 2, 36, 1)
    oled.text("to borrow/return",  2, 48, 1)
    oled.show()


def oled_result(ok, line1, line2):
    oled.fill(0)
    if ok:
        oled.fill_rect(0, 0, 128, 16, 1)
        oled.text("SUCCESS!", 28, 4, 0)
    else:
        oled.rect(0, 0, 128, 16, 1)
        oled.text("WARNING!", 28, 4, 1)
    oled.text(line1[:20], 2, 22, 1)
    oled.text(line2[:20], 2, 36, 1)
    oled.show()


def oled_msg(l1, l2="", l3=""):
    oled.fill(0)
    oled.text(l1[:16], 2,  8, 1)
    oled.text(l2[:16], 2, 24, 1)
    oled.text(l3[:16], 2, 40, 1)
    oled.show()

# ══════════════════════════════════════════════════════════
#   FIREBASE — AUTH & REST API
# ══════════════════════════════════════════════════════════

def fb_authenticate():
    """Sign in with email + password via Firebase Auth REST API."""
    global fb_id_token, fb_token_exp
    url = ("https://identitytoolkit.googleapis.com/v1/accounts"
           ":signInWithPassword?key=" + FIREBASE_API_KEY)
    print("[FB] Authenticating:", FIREBASE_EMAIL)
    print("[FB] Host:", FIREBASE_HOST)
    body = ujson.dumps({
        "email":             FIREBASE_EMAIL,
        "password":          FIREBASE_PASS,
        "returnSecureToken": True
    })
    try:
        r = urequests.post(url, data=body,
                           headers={"Content-Type": "application/json"})
        print("[FB] Auth HTTP:", r.status_code)
        d = r.json()
        r.close()
        if "idToken" in d:
            fb_id_token  = d["idToken"]
            fb_token_exp = get_epoch() + int(d.get("expiresIn", 3600)) - 60
            print("[FB] Auth OK - logged in as", FIREBASE_EMAIL)
            return True
        err = d.get("error", {})
        print("[FB] Auth FAILED code:", err.get("code"), "msg:", err.get("message"))
        return False
    except Exception as e:
        print("[FB] Auth exception:", e)
        return False


def fb_ensure_token():
    """Re-authenticate if token is expired or missing."""
    global fb_id_token
    if not fb_id_token or get_epoch() >= fb_token_exp:
        print("[FB] Token missing - re-authenticating")
        if not fb_authenticate():
            fb_id_token = ""


def fb_url(path):
    """Build a Firebase REST URL - strips accidental https:// from host."""
    host = FIREBASE_HOST.replace("https://", "").replace("http://", "").rstrip("/")
    return "https://{}{}.json?auth={}".format(host, path, fb_id_token)


def fb_get(path):
    """GET a value from Firebase. Returns parsed JSON or None."""
    fb_ensure_token()
    if not fb_id_token:
        print("[FB] GET skipped - no token")
        return None
    print("[FB] GET", path)
    try:
        r = urequests.get(fb_url(path))
        print("[FB] GET status:", r.status_code)
        data = r.json()
        r.close()
        print("[FB] GET result:", data)
        return data
    except Exception as e:
        print("[FB] GET error", path, e)
        return None


def fb_set(path, data):
    """PUT (overwrite) data at a Firebase path. Returns True on success."""
    fb_ensure_token()
    if not fb_id_token:
        return False
    try:
        r = urequests.put(fb_url(path),
                          data=ujson.dumps(data),
                          headers={"Content-Type": "application/json"})
        r.close()
        return True
    except Exception as e:
        print("[FB] SET error", path, e)
        return False


def fb_update(path, data):
    """PATCH (merge update) fields at a Firebase path."""
    fb_ensure_token()
    if not fb_id_token:
        return False
    try:
        r = urequests.patch(fb_url(path),
                            data=ujson.dumps(data),
                            headers={"Content-Type": "application/json"})
        r.close()
        return True
    except Exception as e:
        print("[FB] UPDATE error", path, e)
        return False


def fb_delete(path):
    """DELETE a node at a Firebase path."""
    fb_ensure_token()
    if not fb_id_token:
        return False
    try:
        r = urequests.delete(fb_url(path))
        r.close()
        return True
    except Exception as e:
        print("[FB] DELETE error", path, e)
        return False

# ── Firebase Data Lookups ─────────────────────────────────

def lookup_worker(uid):
    """Return worker name string, or '' if not found."""
    val = fb_get("/workers/{}/name".format(uid))
    if val is None or val == "null":
        return ""
    return str(val)


def lookup_tool(uid):
    """Return tool name string, or '' if not found."""
    val = fb_get("/tools/{}/name".format(uid))
    if val is None or val == "null":
        return ""
    return str(val)


def tool_borrowed_by(tool_uid):
    """Return worker UID who has the tool, or '' if available."""
    val = fb_get("/tools/{}/borrowedBy".format(tool_uid))
    if val is None or val == "null" or val == "":
        return ""
    return str(val)

# ── CHECKOUT ──────────────────────────────────────────────

def do_checkout(w_uid, w_name, t_uid, t_name):
    ts = timestamp()
    ep = get_epoch()

    # 1. Mark tool as borrowed
    if not fb_update("/tools/{}".format(t_uid), {
        "borrowedBy":    w_uid,
        "borrowedAt":    ts,
        "borrowedEpoch": ep,
        "status":        "borrowed"
    }):
        return False

    # 2. Write active loan record
    if not fb_set("/activeLoans/{}/{}".format(w_uid, t_uid), {
        "workerUID":       w_uid,
        "workerName":      w_name,
        "toolUID":         t_uid,
        "toolName":        t_name,
        "checkedOut":      ts,
        "checkedOutEpoch": ep,
        "returned":        False
    }):
        return False

    # 3. Append to history (non-critical — don't fail on error)
    fb_set("/history/{}_{}" .format(ep, t_uid[:4]), {
        "type":       "CHECKOUT",
        "workerUID":  w_uid,
        "workerName": w_name,
        "toolUID":    t_uid,
        "toolName":   t_name,
        "timestamp":  ts,
        "epoch":      ep
    })
    return True

# ── RETURN ────────────────────────────────────────────────

def do_return(w_uid, w_name, t_uid, t_name):
    ts = timestamp()
    ep = get_epoch()

    # 1. Clear tool borrow status
    if not fb_update("/tools/{}".format(t_uid), {
        "borrowedBy":    "",
        "borrowedAt":    "",
        "borrowedEpoch": 0,
        "status":        "available"
    }):
        return False

    # 2. Remove active loan entry
    if not fb_delete("/activeLoans/{}/{}".format(w_uid, t_uid)):
        return False

    # 3. Append to history
    fb_set("/history/{}_{}_R".format(ep, t_uid[:4]), {
        "type":       "RETURN",
        "workerUID":  w_uid,
        "workerName": w_name,
        "toolUID":    t_uid,
        "toolName":   t_name,
        "timestamp":  ts,
        "epoch":      ep
    })
    return True

# ── ALERT ─────────────────────────────────────────────────

def log_alert(alert_type, data):
    fb_set("/alerts/{}_{}".format(get_epoch(), alert_type), data)

# ══════════════════════════════════════════════════════════
#   WIFI & NTP
# ══════════════════════════════════════════════════════════

def connect_wifi():
    global wlan
    wlan = network.WLAN(network.STA_IF)
    wlan.active(True)
    wlan.connect(WIFI_SSID, WIFI_PASSWORD)
    oled_msg("Connecting WiFi", WIFI_SSID[:16], "Please wait...")
    print("[WiFi] Connecting to", WIFI_SSID)
    for _ in range(40):
        if wlan.isconnected():
            break
        time.sleep_ms(500)
        print(".", end="")
    print()
    if not wlan.isconnected():
        print("[WiFi] FAILED!")
        oled_msg("WiFi FAILED!", "Check SSID/Pass", "Restarting...")
        beep_fail()
        time.sleep(3)
        machine.reset()
    ip = wlan.ifconfig()[0]
    print("[WiFi] Connected:", ip)
    oled_msg("WiFi Connected!", ip, "")
    time.sleep_ms(800)


def sync_ntp():
    import ntptime
    ntptime.host = NTP_SERVER
    print("[NTP] Syncing time...")
    for _ in range(15):
        try:
            ntptime.settime()
            print("[NTP] Synced:", timestamp())
            return
        except Exception:
            time.sleep_ms(500)
    print("[NTP] Sync failed — using internal clock")

# ══════════════════════════════════════════════════════════
#   SETUP
# ══════════════════════════════════════════════════════════

def setup():
    print("=" * 40)
    print("  SMART TOOL MANAGEMENT SYSTEM")
    print("  MicroPython + Firebase REST")
    print("=" * 40)

    oled_msg("Booting...", "Tool System", "Please wait")
    time.sleep_ms(800)

    # Step 1: WiFi
    connect_wifi()

    # Step 2: NTP time sync
    sync_ntp()

    # Step 3: Firebase auth
    oled_msg("Firebase...", "Authenticating", "Please wait")
    if not fb_authenticate():
        oled_msg("Firebase FAILED", "Check config.py", "Restarting...")
        beep_fail()
        time.sleep(3)
        machine.reset()

    print("[READY] System ready — waiting for scan")
    beep_welcome()
    oled_idle()

# ══════════════════════════════════════════════════════════
#   MAIN LOOP
# ══════════════════════════════════════════════════════════

def loop():
    global sys_state, worker_uid, worker_name, state_timer

    while True:

        # ──────────────────────────────────────────────────
        #  STATE: IDLE — waiting for worker ID card
        # ──────────────────────────────────────────────────
        if sys_state == STATE_IDLE:

            stat, tag_type = rfid.request(rfid.REQIDL)
            if stat != rfid.OK:
                time.sleep_ms(50)
                continue

            stat, raw_uid = rfid.anticoll()
            if stat != rfid.OK:
                time.sleep_ms(50)
                continue

            uid = rfid_uid(raw_uid)
            rfid.halt_a()
            print("[SCAN] ID Card UID:", uid)

            # Check Firebase token
            if not fb_id_token:
                oled_result(False, "Firebase offline", "Check WiFi")
                beep_fail()
                time.sleep_ms(3000)
                oled_idle()
                continue

            # Look up worker
            name = lookup_worker(uid)
            if not name:
                print("[WARN] Unknown card:", uid)
                oled_result(False, "Unknown ID card!", uid[:16])
                beep_alarm()
                log_alert("UID", {
                    "uid":       uid,
                    "timestamp": timestamp(),
                    "type":      "UNKNOWN_ID"
                })
                time.sleep_ms(3000)
                oled_idle()
                continue

            # Valid worker
            worker_uid  = uid
            worker_name = name
            sys_state   = STATE_ID_SCANNED
            state_timer = time.ticks_ms()
            beep_welcome()
            oled_welcome(name)
            print("[OK] Worker identified:", name)
            continue

        # ──────────────────────────────────────────────────
        #  STATE: ID_SCANNED — waiting for tool tag
        # ──────────────────────────────────────────────────
        if sys_state == STATE_ID_SCANNED:

            # 15 second timeout
            if time.ticks_diff(time.ticks_ms(), state_timer) > ID_TIMEOUT:
                print("[TIMEOUT] No tool scanned — resetting")
                oled_result(False, "Timed out!", "Scan ID again")
                beep_fail()
                sys_state   = STATE_IDLE
                worker_uid  = ""
                worker_name = ""
                time.sleep_ms(2000)
                oled_idle()
                continue

            stat, tag_type = rfid.request(rfid.REQIDL)
            if stat != rfid.OK:
                time.sleep_ms(50)
                continue

            stat, raw_uid = rfid.anticoll()
            if stat != rfid.OK:
                time.sleep_ms(50)
                continue

            t_uid = rfid_uid(raw_uid)
            rfid.halt_a()
            print("[SCAN] Tool UID:", t_uid)

            # Guard: worker re-scanned own ID card
            if t_uid == worker_uid:
                oled_result(False, "That is your ID!", "Scan a tool tag")
                beep_fail()
                time.sleep_ms(2000)
                oled_welcome(worker_name)
                continue

            sys_state = STATE_PROCESSING
            oled_msg("Processing...", "Please wait...", "")

            # Look up tool name
            t_name = lookup_tool(t_uid)
            if not t_name:
                print("[WARN] Unknown tool tag:", t_uid)
                oled_result(False, "Unknown tool!", "Register first")
                beep_alarm()
                log_alert("TOOL", {
                    "uid":        t_uid,
                    "scannedBy":  worker_uid,
                    "workerName": worker_name,
                    "timestamp":  timestamp(),
                    "type":       "UNKNOWN_TOOL"
                })
                time.sleep_ms(3000)
                sys_state   = STATE_IDLE
                worker_uid  = ""
                worker_name = ""
                oled_idle()
                continue

            # ── Auto-detect: borrow or return? ─────────────
            borrowed_by = tool_borrowed_by(t_uid)

            if borrowed_by == "":
                # ── CHECKOUT ─────────────────────────────
                print("[ACTION] CHECKOUT:", worker_name, "->", t_name)
                if do_checkout(worker_uid, worker_name, t_uid, t_name):
                    oled_result(True, "CHECKED OUT", t_name[:16])
                    beep_ok()
                else:
                    print("[ERROR] Checkout failed")
                    oled_result(False, "DB write error", "Try again")
                    beep_fail()

            elif borrowed_by == worker_uid:
                # ── RETURN ───────────────────────────────
                print("[ACTION] RETURN:", worker_name, "returned", t_name)
                if do_return(worker_uid, worker_name, t_uid, t_name):
                    oled_result(True, "RETURNED!", t_name[:16])
                    beep_ok()
                else:
                    print("[ERROR] Return failed")
                    oled_result(False, "DB write error", "Try again")
                    beep_fail()

            else:
                # ── CONFLICT: tool with someone else ─────
                other = lookup_worker(borrowed_by) or borrowed_by
                print("[CONFLICT]", t_name, "is with", other)
                oled_result(False, "Tool held by:", other[:16])
                beep_alarm()
                log_alert("CONF", {
                    "toolUID":           t_uid,
                    "toolName":          t_name,
                    "attemptedByUID":    worker_uid,
                    "attemptedByName":   worker_name,
                    "currentlyWithUID":  borrowed_by,
                    "currentlyWithName": other,
                    "timestamp":         timestamp(),
                    "type":              "CONFLICT"
                })
                time.sleep_ms(3000)
                sys_state   = STATE_IDLE
                worker_uid  = ""
                worker_name = ""
                oled_idle()
                continue

            # Reset after result display
            time.sleep_ms(MSG_SHOW)
            sys_state   = STATE_IDLE
            worker_uid  = ""
            worker_name = ""
            oled_idle()

# ══════════════════════════════════════════════════════════
#   ENTRY POINT
# ══════════════════════════════════════════════════════════
setup()
loop()

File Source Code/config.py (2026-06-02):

# ╔══════════════════════════════════════════════════════════╗
#   config.py — Firebase + WiFi credentials
#   Save this file to the ROOT of your ESP32 via Thonny
#   (same folder as main.py)
# ╚══════════════════════════════════════════════════════════╝

# ── WiFi ──────────────────────────────────────────────────
WIFI_SSID     = "YOUR_WIFI_NAME"        # ← replace with your WiFi name
WIFI_PASSWORD = "YOUR_WIFI_PASSWORD"    # ← replace with your WiFi password

# ── Firebase — YOUR REAL PROJECT VALUES ───────────────────
# ⚠ FIREBASE_HOST must NOT start with https://
# ⚠ FIREBASE_HOST must NOT have a trailing slash /

FIREBASE_HOST    = "YOUR_FIREBASE_HOST" # ← host you created in Firebase
FIREBASE_API_KEY = "YOUR_FIREBASE_API_KEY" # ← API key you created in Firebase 
FIREBASE_EMAIL   = "YOUR_AUTH_EMAIL"    # ← email you created in Firebase Auth
FIREBASE_PASS    = "YOUR_AUTH_PASSWORD" # ← that email's password
